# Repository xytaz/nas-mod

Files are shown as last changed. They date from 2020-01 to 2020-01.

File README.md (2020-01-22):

# NAS Mod

## Description

This project started with the objective to turn a USB RAID storage system into a NAS (Network-Attached Storage) unit. In reality, it was more of a (very much needed) exercise in embedded Linux.

The essence of the idea is to modify a [GR3680-SB3](https://www.raidsonic.de/products/external_cases/soho_raid/index_en.php?we_objectID=2984) by replacing the proprietary board with a Raspberry Pi or an ODROID-XU4. This involves:

  - Connecting the LCD, control buttons, and LED's to the new board(s) properly.
  - Interfacing Linux with this extra hardware.
  - Writing a piece of code to make use of it.

Given how surprisingly scarce, scattered, cryptic, or incomplete Linux resources on this subject can be (at least for an advanced beginner), this repo serves not only as a reference for this particular implementation but also as a tutorial for interacting with basic hardware in Linux. The emphasis is not on NAS software itself.

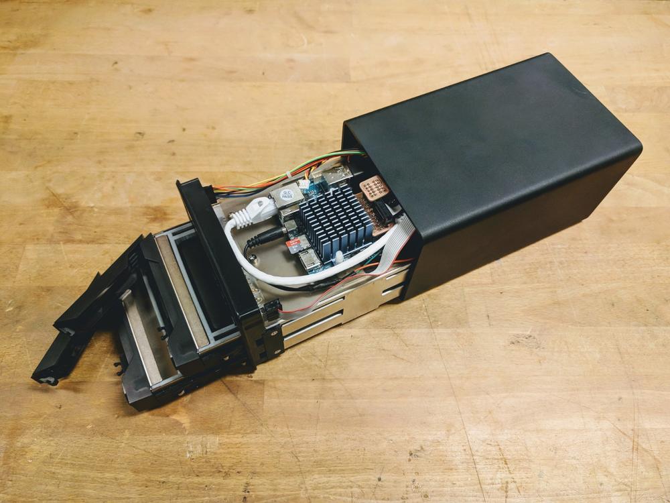
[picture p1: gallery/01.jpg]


## Quick guide

There is a number of Makefile's to automate the setup. Keep in mind that several parameters are hard-coded and things may easily break. See the detailed documentation when that happens.

Assuming you have [Linux set up](docs/02-linux-setup.md) properly, clone this repo and run `make` in each of the following directories and then reboot at the end:

- Pi
    ```
    /code/02-device-tree/pi
    /code/03-python
    /code/04-systemd-service # (manually change path in Makefile)
    ```
- XU4
    ```
    /code/01-modules
        # make NAME=charlcd
        # make NAME=charlcd
        # echo 'charlcd' | sudo tee -a /etc/modules
        # echo 'hd44780' | sudo tee -a /etc/modules
        # sudo depmod

    /code/02-device-tree/xu4
    /code/03-python
    /code/04-systemd-service # (manually change path in Makefile)
    ```

## Detailed documentation

_aka: The Missing Tutorial on How to Use Basic Hardware in Linux_

- [Hardware](docs/01-hardware.md)
- [Linux setup](docs/02-linux-setup.md)
- [How to interact with GPIO's](docs/03-gpios.md)
- [Drivers and modules](docs/04-drivers-modules.md)
- [Device tree](docs/05-device-tree.md)
- [Testing](docs/06-testing.md)
- [Python](docs/07-python.md)
- [Auto-start script](docs/08-autostart.md)

## Known issues

- Jittery backlight on startup, power off, and more.
- LCD animation better when looking at some angles (but not straight on).
- Scrolling with values that change frequently (multiple values in a line or temperature).
- Clock skipping a second occasionally.
- Last message remains after power off then on
- Not sure where these default messages come from:
    - Kernel version on startup.
    - "Power off" on shutdown.
    - "LCD driver unloaded" when `hd44780` module is removed, e.g. with `rmmod`.
    - "Reloading System ..." on reboot.

## Gallery

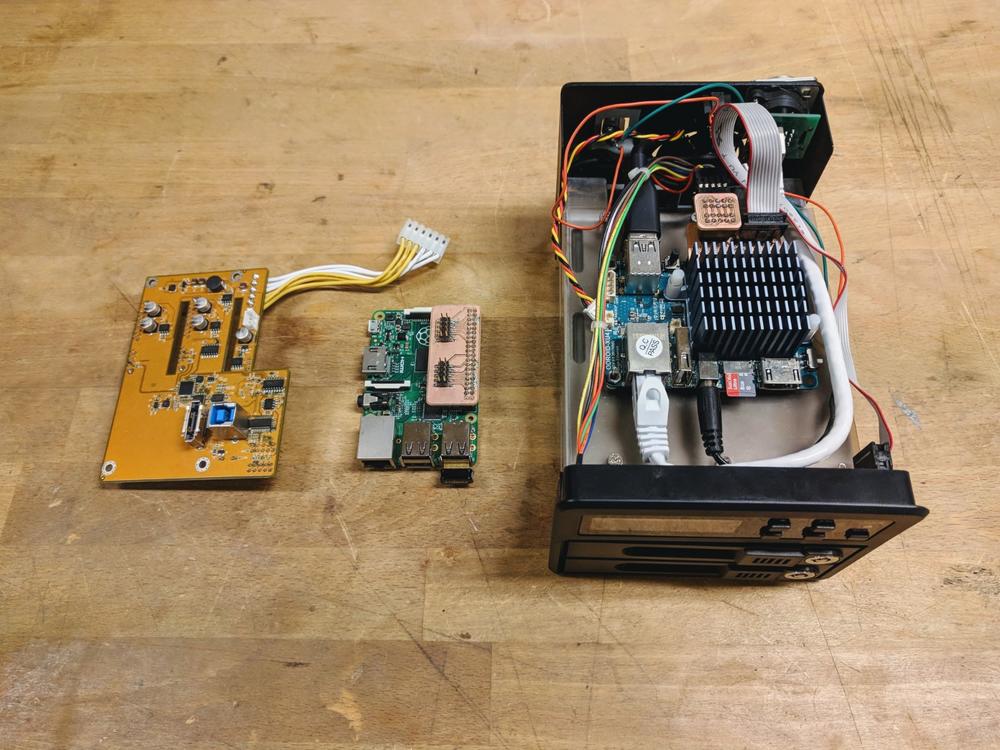
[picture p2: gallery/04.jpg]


_                   |_
--------------------|--------------------
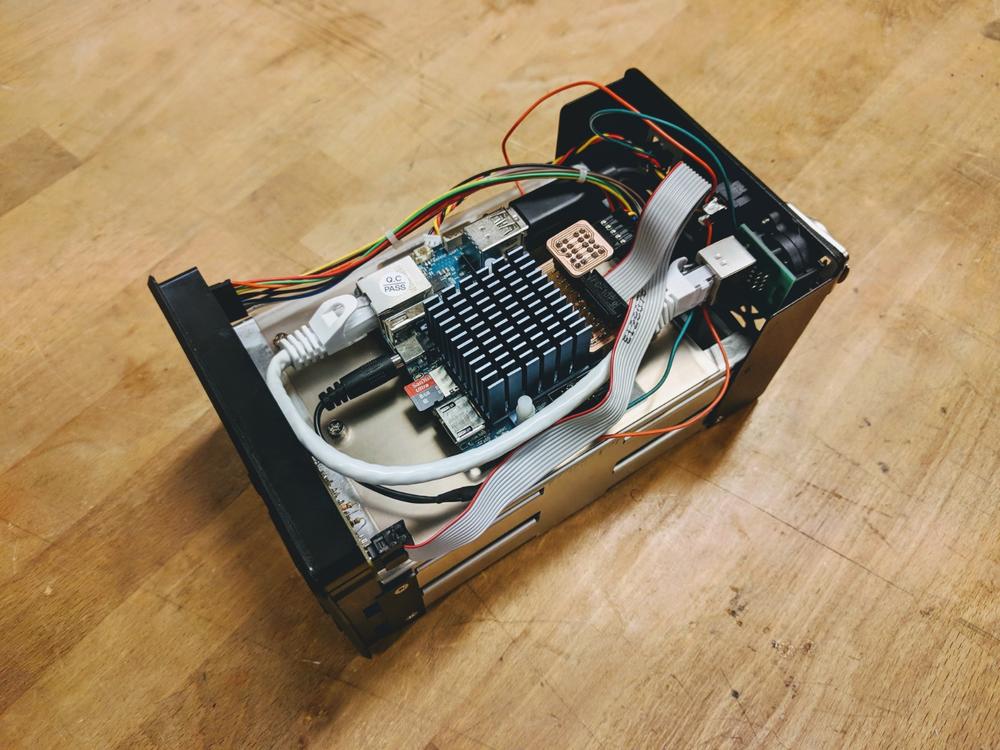
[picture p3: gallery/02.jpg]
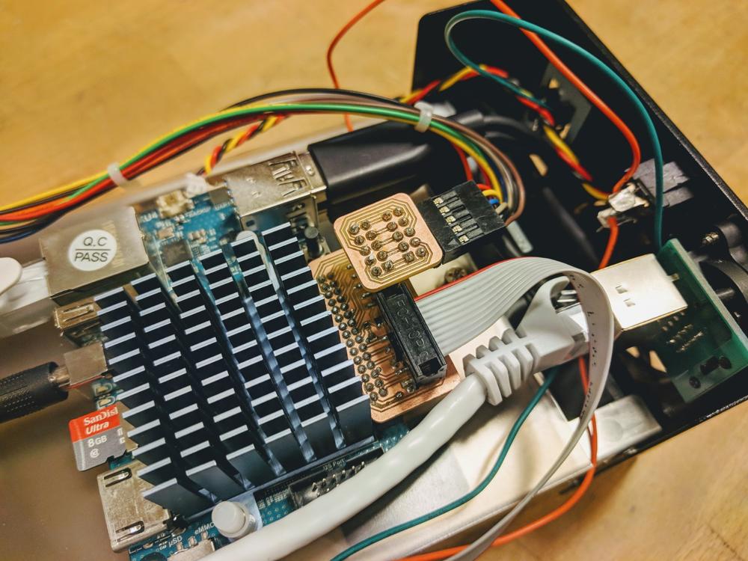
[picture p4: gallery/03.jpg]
 |  
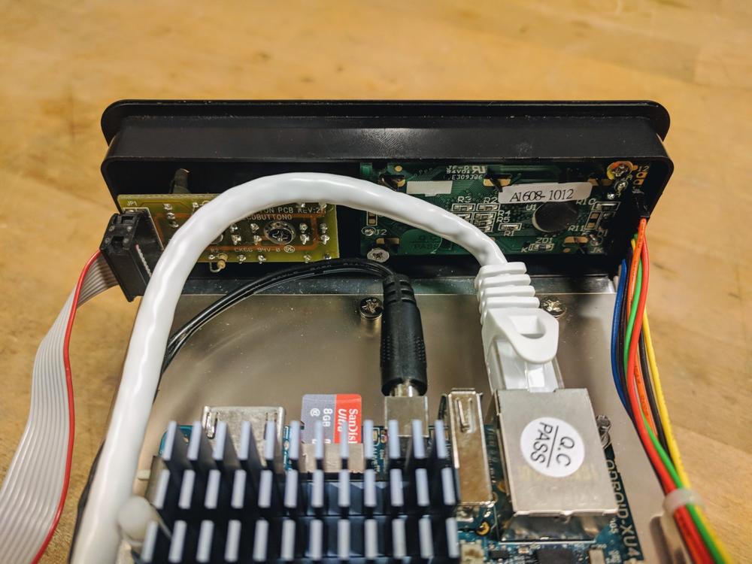
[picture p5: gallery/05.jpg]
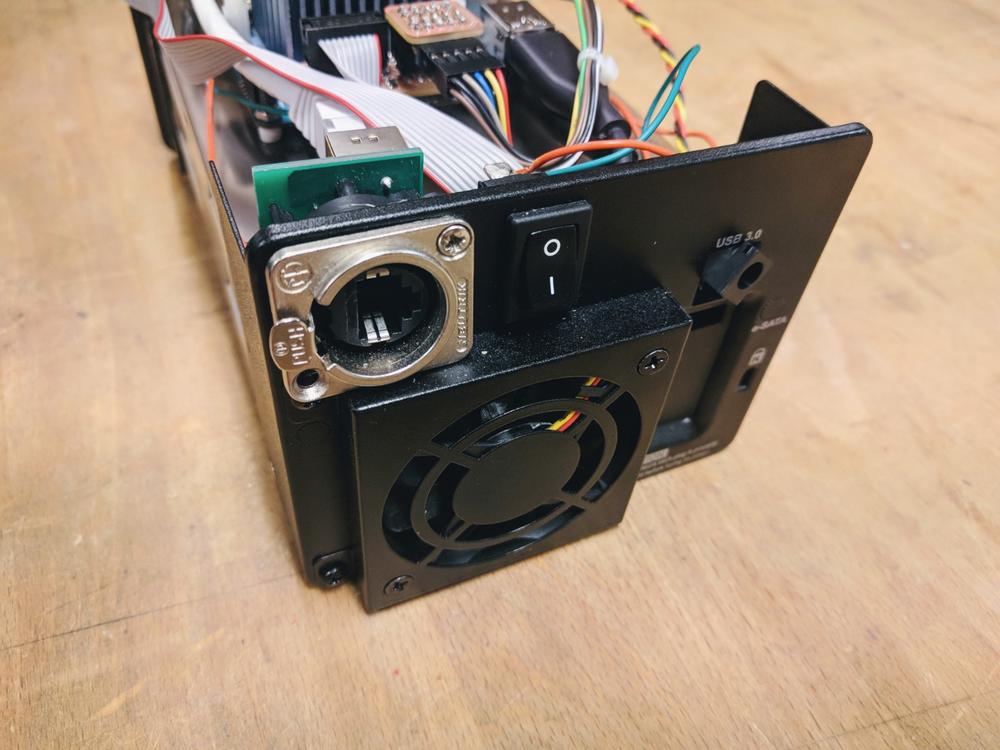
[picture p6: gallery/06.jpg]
 |  
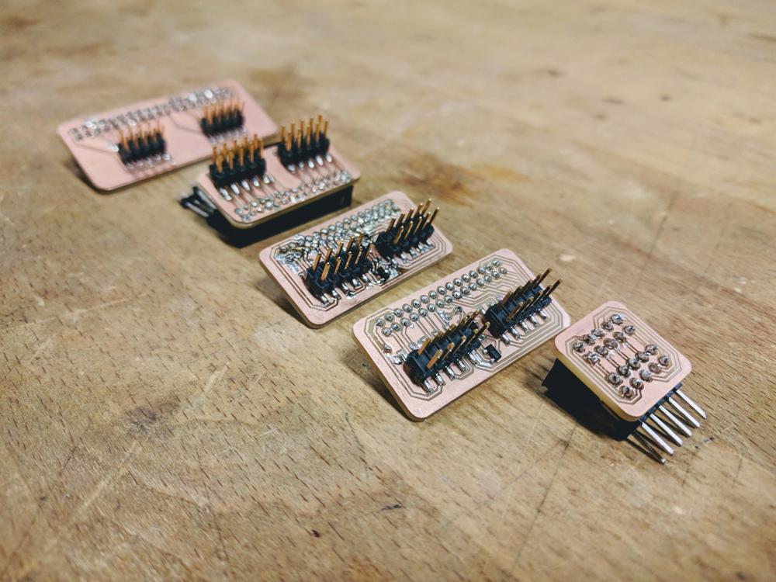
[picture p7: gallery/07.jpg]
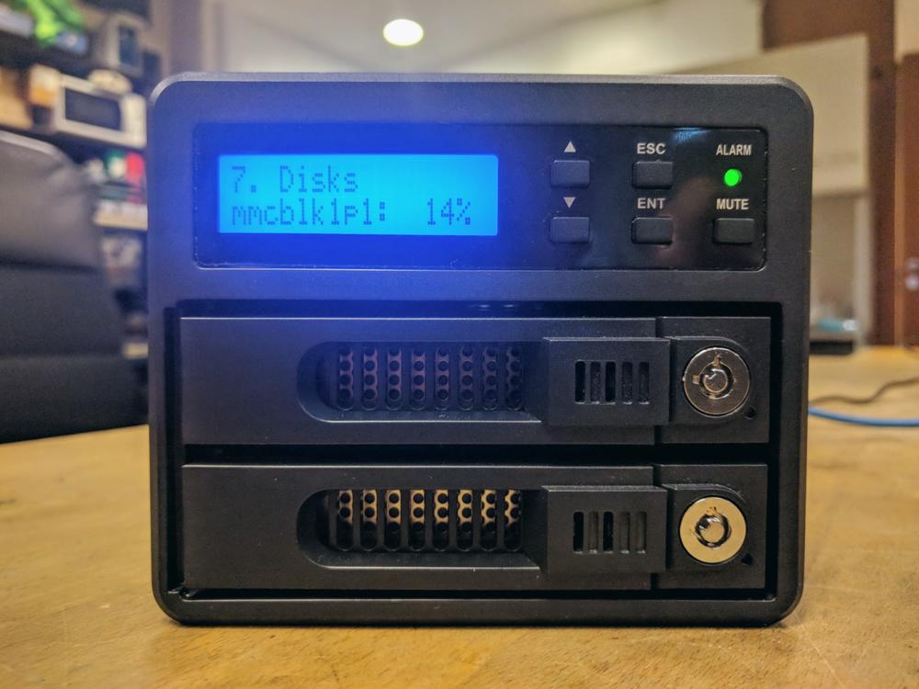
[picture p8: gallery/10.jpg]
 |

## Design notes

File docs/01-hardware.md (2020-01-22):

# NAS Mod

## Hardware

### 1. Boards

The two boards used in this project are:

- [Raspberry Pi 1 B+](https://www.adafruit.com/product/1914)
- [ODROID-XU4](https://wiki.odroid.com/odroid-xu4/odroid-xu4)

The Pi was used for prototyping even if the XU4 was meant to be the final board from the beginning. The setup on each is equivalent but not identical, as will be clear next. You obviously need only one of them.

### 2. LCD, buttons, and LED's

The GR3680-SB3 comes with:

- 16x2 LCD with the [HD44780 controller](https://en.wikipedia.org/wiki/Hitachi_HD44780_LCD_controller)
- 4 push buttons and 1 toggle button
- 2 LED's (red and green)

On the original board, the hard drives have SATA connectors and there is no way to get on a netowrk. With this mod, the actual hard drives are connected through USB. Access to the network can be done via ethernet or a [USB WiFi adapter](https://www.edimax.com/edimax/merchandise/merchandise_detail/data/edimax/global/wireless_adapters_ac1200_dual-band/ew-7822ulc/).

### 3. Connector boards

The LCD has its own connector while the buttons and LED's share one. Simple breakout boards can be milled or manufactured to connect to GPIO pins:

- [Pi pinout](https://www.raspberrypi.org/documentation/usage/gpio/)
- [XU4 pinout](https://wiki.odroid.com/odroid-xu4/hardware/expansion_connectors)

Note that:

- CON10 on the XU4 has a 2-mm pitch, which does not match the typical 2.54-mm pin spacing.
- The XU4 is a [1.8V board](https://forum.odroid.com/viewtopic.php?t=18531), which turns out to be insufficient to turn on the green LED (but surprisingly enough for the LCD data lines), hence the need for level shifting on one of the pins. There are [shields](https://www.hardkernel.com/shop/xu4-shifter-shield/) that do just that, but that is overkill for our purposes.

See the `/pcb` directory for KiCad files.

### Helpful links

- https://hackaday.com/2016/12/05/taking-it-to-another-level-making-3-3v-and-5v-logic-communicate-with-level-shifters/
- https://www.i-programmer.info/programming/hardware/9105-exploring-edison-life-at-18v.html?start=1

```
@TODO: Put somewhere

works
https://www.nexperia.com/products/bipolar-transistors/general-purpose-bipolar-transistors/transistors-single-npn/BC847C.html

weird behavior
https://cdn.sparkfun.com/datasheets/BreakoutBoards/BSS138.pdf

Also, replace symbol of transistor in schematic.
```

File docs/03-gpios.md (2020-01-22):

# NAS Mod

## How to interact with GPIO's

Two possible approaches to interact with GPIO's on a single-board computer (SBC) are:

  1. Using custom libraries designed specifically for this reason.
  2. _"The proper way",_ that is, through Linux drivers, device trees, and overlays.

The first option is generally easier but more limited. Also, more library support exists for the Raspberry Pi than any other SBC, whereas device trees are standard in every Linux kernel (with some differences).

### 1. Approach I: GPIO libraries (explored but not used)

- [gpiozero](https://gpiozero.readthedocs.io/en/stable/) is the official library for the Pi, at least it comes bundled with Raspbian Desktop. It does not support other boards.
- [WiringPi](http://wiringpi.com/) is another library designed originally for the Pi but has been [forked to support the XU4](https://wiki.odroid.com/odroid-xu4/application_note/gpio/wiringpi) in both C and Python.

Installation on the Pi is pretty straightforward. For the XU4, the following tips may save you an hour or two:
```
# Run `sudo` with all of these even if you get no complaints.
# You may get weird behavior in silence if you do not.
pip3 install --upgrade setuptools
pip3 install wheel
apt install python3-dev
pip3 install odroid-wiringpi
```

This approach was not pursued beyond installation and running a couple examples to control the LCD since it is the least simple.

Helpful links:
  
  - @REALLY_GOOD
  - [tutorials-raspberrypi.com](https://tutorials-raspberrypi.com/raspberry-pi-lcd-display-16x2-characters-display-hd44780/)
  - [glennklockwood.com](https://www.glennklockwood.com/electronics/hd44780-lcd-display.html)

  - [learn.adafruit.com](https://learn.adafruit.com/drive-a-16x2-lcd-directly-with-a-raspberry-pi?view=all)
  - [github.com](https://github.com/WiringPi/WiringPi-Python)

  - @REALLY_GOOD life savers
  - [odroid.com](https://odroid.com/dokuwiki/doku.php?id=en:16x2_lcd_io_shield)
  - [odroid.com](https://odroid.com/dokuwiki/doku.php?id=en:xu4_16x2lcd_example)

### 2. Approach II: Device trees, etc. (used)

**The short story is** that you want to be able to control hardware through the command line, typically by interacting with a _"device file"_. For this to happen (i.e. exposing that hardware to _"userspace"_), it needs to be added as a _"node"_ in the _"device tree"_. The device tree can be edited directly or, if supported, have "_device tree overlays"_ loaded on top of it on-the-fly. In either case, a device tree node needs to reference a _"driver"_ that describes how the hardware works. You could write your own drivers, but the Linux kernel comes with quite a few that may match your needs. Some of these drivers may be loaded into your particular instance of the kernel and ready to use and some not. If they are not, the corresponding _"modules"_ will need to be compiled, copied to the kernel, and enabled.

If this seems complicated, it is not, but it is the meat of this project and what took most of the time to figure out. Let us take it step by step, starting from the very end.

### Helpful links

- [All about sysfs vs. chardev](https://www.youtube.com/watch?v=lQRCDl0tFiQ)
- https://blog.adafruit.com/2018/11/26/sysfs-is-dead-long-live-libgpiod-libgpiod-for-linux-circuitpython/
- https://www.beyondlogic.org/an-introduction-to-chardev-gpio-and-libgpiod-on-the-raspberry-pi/
- https://kernel.googlesource.com/pub/scm/libs/libgpiod/libgpiod/+/v0.2.x/README.md

```
@TODO: Put somewhwere

options for interacting with gpio:
  1. [raspberry pi libraries](https://www.raspberrypi.org/documentation/usage/gpio/python/README.md)
  1. sysfs
  1. chardev, libgpiod
  1. gpio-keys
```

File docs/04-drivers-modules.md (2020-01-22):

# NAS Mod

## Drivers and modules

### 1. Check your drivers

1. First, check what drivers are ready for you to use in the kernel
```
# Find kernel version by running `uname -r`
# or more system info with `uname -a`.
> ls /lib/modules/<<KERNEL>>/kernel/drivers/
```

2. Make sure you have the following files/directories
```
# LCD
/lib/modules/<<KERNEL>>/kernel/drivers/auxdisplay/hd44780.ko
/lib/modules/<<KERNEL>>/kernel/drivers/auxdisplay/charlcd.ko
# Keys
/lib/modules/<<KERNEL>>/kernel/drivers/gpio
# LEDS
/lib/modules/<<KERNEL>>/kernel/drivers/leds
```

3. If you are using the **Pi**, go grab coffee and skip to the next section (unless any of the above is missing). If you are using the **XU4**, you get to learn more about how Linux works.

### 2. Compile your modules, enable your drivers

1. Install build tool and the correct [Linux headers](https://wiki.gentoo.org/wiki/Linux-headers)

```
> apt-get install build-essential

# Search for available header packages
> apt-cache search headers odroidxu4

# Or just go for this one
> sudo apt-get install linux-headers-current-odroidxu4
# Linux kernel headers for 5.4.7-odroidxu4 on armhf
```

2. Pull the directory `/code/modules` from this repo and navigate to it.

3. Grab modules source code

```
wget https://raw.githubusercontent.com/torvalds/linux/master/drivers/auxdisplay/charlcd.h
wget https://raw.githubusercontent.com/torvalds/linux/master/drivers/auxdisplay/charlcd.c
wget https://raw.githubusercontent.com/torvalds/linux/master/drivers/auxdisplay/hd44780.c
```

4. Compile the modules and copy the `.ko` files to the correct spot (kernel drivers directory)

```
# IMPORTANT: Run `sudo su` then run these commands.
# Does not work with regular `sudo` for some reason.
make NAME=charlcd
make NAME=hd44780
# All should be good if the last line of output does not contain the word `Error`.
```

5. (Optional) Test if the modules load properly
```
# Insert module: `insmod module.ko`
# Remove module: `rmmod module`
make test NAME=charlcd
make test NAME=hd44780
```

6. Set up modules to load on startup automatically
```
echo 'charlcd' | sudo tee -a /etc/modules
echo 'hd44780' | sudo tee -a /etc/modules
sudo depmod
```

7. Reboot
```
sudo shutdown -r now
```

8. Check if modules loaded
```
lsmod
```

9. Use `dmesg` to check any errors in the process. You may also need to debug your module at some point. Use `printk("something")` in the `.probe` function in `module.c` before compiling to `.ko` and putting it in the kernel drivers directory. Those messages will appear in `dmesg`.

### Helpful links:

- @REALLY_GOOD LKM tutorial (very good? excellent)
  - https://blog.sourcerer.io/writing-a-simple-linux-kernel-module-d9dc3762c234
  - https://stackoverflow.com/questions/4356224/how-to-load-a-custom-module-at-the-boot-time-in-ubuntu
- @REALLY_GOOD hepled a lot
  - http://swap.web.elte.hu/lcdproject/driver_en.html
  - https://www.linuxjournal.com/article/6568
  - http://linuxdocs.org/HOWTOs/Kernel-HOWTO-4.html
- headers
  - https://www.raspberrypi.org/forums/viewtopic.php?t=67347
  - https://apt.armbian.com/pool/main/l/
- https://github.com/torvalds/linux/blob/master/Documentation/devicetree/bindings/auxdisplay/hit%2Chd44780.txt

```
@TODO: Put somewhere

find / -name modprobe
/sbin/modprobe hd44780

- Config the kernel
  - Steps:
    - `cd /usr/src/linux-headers-5.4.7-odroidxu4/`
    - if you feel like it `make config` but we won't go there
    - `sudo apt install libncurses-dev`
    - `make menuconfig`
      - Device Drivers
      - Auxiliary Display Support (press Y or space without going into the item itself) ~Then go in again~ and enable HD44780?
      - 

# You may also find these files in here
# /lib/modules/<<KERNEL>>/build/drivers/

This is not sarcastic. Really.
  - `If you don't understand what all this is about, say N.`

recompile kernel?
  - /proc/config.gz
  - look up "gen2"

  for future:
  - compile kernel
    http://www.ibiblio.org/elemental/howto/kernel-rebuild.html
```

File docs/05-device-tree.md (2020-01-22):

# NAS Mod

## Device trees and overlays

### 1. The basics

Each system loads up a base device tree file in the format `.dtb` (device tree binary blob) which contains all the hardware nodes defined.

- First, you can see the effects of the device tree loaded.
```
ls /proc/device-tree/
```

- There does not seem to be a one-step way to track down the actual `.dtb` file, but it is not that difficult. A big hint is the model name.
```
cat /proc/device-tree/model
```

- `.dtb` files are typically somewhere under the `/boot` directory. You should be able to identify the correct `.dtb` file based on the model name you have.
```
# Pi
/boot/bcm2708-rpi-b-plus.dtb
# XU4
/boot/dtb/exynos5422-odroidxu4.dtb
```

- You can convert a `.dtb` file into `.dts`, a human-readable device tree source file.
```
# From blob to source
dtc -O dts -o output.dts input.dtb # or .dtbo
```

- Ideally, you would not want to touch the base `.dts`. This is where overlays come into the picture. These are files with only additional nodes that should be added to the base device tree on-the-fly. An overlay file starts as a `.dts` and should be compiled to a `.dtbo` file.
```
# From source to blob
dtc -O dtb -o output.dtbo input.dts # or .dtb
```

- Overlays are not supported on all systems. You can till by the existence of a `/boot/overlays` directory. The good news is you get to see how both ways work since the Pi has it and the XU4 does not.

Before you continue, it is worth getting familiar with device tree structure and conventions. Keep the following links handy as you go through the upcoming steps:

  - https://elinux.org/Device_Tree_Reference
  - https://elinux.org/Device_Tree_Usage
  - https://www.raspberrypi.org/documentation/configuration/device-tree.md

### 2. Make changes

- With overlays (Pi)

  1. Create `dts` file(s)
  2. Compile to `dtbo`
  3. Copy to `/boot/overlays`
  4. Enable overlays in `/boot/config.txt`
  5. Disable conflicting nodes (I2C)
  6. Reboot

- Without overlays (XU4)

  1. Decompile base device tree `.dtb`
  2. Add nodes to `.dts`
  3. Compile back to `.dtb`
  4. Disable conflicting nodes (SPI)
  5. Copy to original spot (`boot/dtb`)
  6. Reboot

Navigate to `/code/device-tree` and check out the files there or simply run `make` in the corresponding directory for these steps to execute.

If you decide to take a look at the files mentioned, here is a quick summary of the main differences between the Pi and XU4:

| | Pi | XU4 |
| --- | --- | --- |
| Overlays | Supported | Not supported |
| DT location | `/boot/` and `/boot/overlays` | `/boot/dtb`|
| Use of `&gpio` | Enabled | Have to use `phandle` of `gpx1`, etc. | 
| Numbers | Decimal | Hex |

#### 2.1 Pin numbering

If you take a look at the [pinout of, say, the XU4](https://wiki.odroid.com/odroid-xu4/hardware/expansion_connectors), you will see quite a few ways to refer to a pin:
  1. Pin number
  2. GPIO number
  3. WiringPi Number
  4. xN.M format (or whatever it is actually called)

The second and the fourth are the ones used here, summarized (nicely!) in the table below:

```
| ------- | ----- | ---------- | ---- | -------------------------- |
|         | label |  key code  |  pi  |  xu4       (PCP* PN**)     |
| ------- | ----- | ---------- | ---- | -------------------------- |
| sw2     |  dwn  |     108    |  19  |  24  x2.0  (0x48 0x00)     |
| sw3     |  up   |     103    |   6  |  25  x2.1  (0x48 0x01)  +  |
| sw5     |  ent  |      28    |   0  |  31  x2.7  (0x48 0x07)     |
| sw1a    |  mute |      58    |  11  | 174  a0.3  (0xb0 0x03)     |
| sw4     |  esc  |       1    |   9  |  28  x2.4  (0x48 0x04)     |
| ------- | ----- | ---------- | ---- | -------------------------- |
| led2    |  red  |            |  13  |  23  x1.7  (0x4a 0x07)     |
| led1    |  grn  |            |   5  |  19  x1.3  (0x4a 0x03)     |
| ------- | ----- | ---------- | ---- | -------------------------- |
| rst     |       |            |  22  | 210  b3.3  (0xcf 0x03)     |
| en      |       |            |  27  | 209  b3.2  (0xcf 0x02)     |
| d4      |       |            |  17  | 189  a2.4  (0x47 0x04)     |
| d5      |       |            |   4  | 172  a0.1  (0xb0 0x01)     |
| d6      |       |            |   3  | 171  a0.0  (0xb0 0x00)     |
| d7      |       |            |   2  | 173  a0.2  (0xb0 0x02)  +  |
| ------- | ----- | ---------- | ---- | -------------------------- |
 * Pin controller phandle (in hex). Values may change from system to system.
   Check `/code/device-tree/xu4/nas-nodes.txt` to see how these values are found.
** Pin number (in hex), e.g. the "1" in "x3.1".
```

#### 2.2 What is _"Disable conflicting nodes"_ all about?

**Symptoms**

  - (Pi) Gibberish output on the LCD.
  - (XU4) Failure to load the LCD module. Running `dmesg` results in:
  ```
  hd44780: probe of auxdisplay failed with error -16
  ```

**Debugging**

Error 16 indicates that two processes are trying to access the same resource at the same time.

Placing `printk` messages and checking `dmesg`, as described in the section discussing drivers and modules, points to the point of failure, i.e. one of the pins failing to register properly.

Running `gpioinfo` (`apt-get install gpiod`) will show which pins are busy and by what.

Note: Debugging on the XU4 was more systematic. It was more based on hunch with the Pi, since the symptoms and results of the previous debugging steps differ significantly.

**Diagnosis**

Some pins double as regular GPIO's as well as special-purpose pins. It happens that a few of the pins are also for I2C (Pi) and SPI (XU4). This depends entirely on which pins you decide(d) to use.

**Solution**

You could choose to use only pure GPIO pins, but that is not necessary in this case.

- With overlays (Pi)
  - Disable the offending node in `/boot/config.txt`
  ```
  # Change from ...
  dtparam=i2c_arm=on
  # ... to
  dtparam=i2c_arm=off
  ```

- Without overlays (XU4)
  - Option I: _Manually_ disable the offending node in the base device tree
  ```
  # Change from ...
  spidev@0 {
        status = "okay";
  # ... to
  spidev@0 {
        status = "disabled";
  ```

  - Option 2: Disable it slightly [more elegantly](https://developer.ridgerun.com/wiki/index.php/Edit_device_tree_at_run_time) (on the `.dtb` not `.dts`)
  ```
  fdtput exynos5422-odroidxu4.dtb spi1/spidev@0 status disabled
  # Also check out `fdtget` to read values.
  ```

### Helpful links

- https://yeah.nah.nz/embedded/linux-chardev-lcd/
- http://blog.gegg.us/2017/01/setting-up-a-gpio-button-keyboard-on-a-raspberry-pi/
- https://reitmaier.xyz/blog/matrix_keyboard/
- http://blog.gegg.us/2017/08/a-matrix-keypad-on-a-raspberry-pi-done-right/
- https://www.acmesystems.it/CM3-HOME_rgbled
- http://xillybus.com/tutorials/device-tree-zynq-1
- https://elinux.org/images/e/e5/Dt_debugging_part_3.pdf
- https://www.milesburton.com/USD_LCD_Display_(HD44780)_Running_on_Linux_via_Arduino
- https://www.rototron.info/lcdproc-tutorial-for-raspberry-pi/
- https://stackoverflow.com/questions/21670967/how-to-compile-dts-linux-device-tree-source-files-to-dtb
- When you decide to give up and RTFM
  - https://elinux.org/Device_Tree_Reference
  - https://elinux.org/Device_Tree_Usage
  - https://elinux.org/Device_Tree_Source_Undocumented
  - https://www.raspberrypi.org/documentation/configuration/device-tree.md
  - https://www.kernel.org/doc/Documentation/devicetree/bindings/input/gpio-keys.txt
  - https://github.com/torvalds/linux/blob/master/Documentation/devicetree/bindings/auxdisplay/hit%2Chd44780.txt
  - https://www.kernel.org/doc/Documentation/devicetree/bindings/pinctrl/pinctrl-bindings.txt
  - https://www.kernel.org/doc/Documentation/devicetree/bindings/pinctrl/brcm,bcm2835-gpio.txt
  
```
@TODO: Put somewhere
user space vs. kernel space (device tree is kernel space)

sudo find /sys/ -name *pin*
ls /sys/kernel/debug/pinctrl
find /sys/ -name *pinmux*
sudo cat /sys/kernel/debug/pinctrl/

http://wiringpi.com/the-gpio-utility/
gpio readall -a
```

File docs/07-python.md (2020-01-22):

# NAS Mod

## Python

### TITLE?

To set up the environment, navigate to `/code/python` and run with `sudo`:

```
apt-get update
apt-get -y install python3-pip
pip3 install -r requirements.txt
python3 nas.py
```

To make changes to the code, your entry point is `/code/python/nas.py`. The files should be straightforward to navigate.

To make it easy to grasp what is going on:

- The LCD has a list of screens and an index to track which screen is currently active.
- Each screen has a list of lines.
- Each line has a list of values and an index to track which value is currently active.
- The value of a line can be static (string or list of strings) or dynamic (function).
- There is a set of threads to listen to presses of specific keys.
- There is a refresh thread that constantly checks if the values of dynamic lines have changed.
- There is a scrolling thread, which can be disabled, to horizontally scroll content that is longer than the screen can display.

### Helpful links
- [LCD Arduino video tutorial](https://www.youtube.com/watch?v=Q58mQFwWv7c)
- [LCD Pi video tutorial](https://www.youtube.com/watch?v=cVdSc8VYVBM)

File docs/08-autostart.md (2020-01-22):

# NAS Mod

## Auto-start script

### `systemd` service

Lastly, one of the ways to run a script on startup is by creating a `systemd` service.

See `/code/service/nas.service` for an example to use with the following steps.

1. Create a `<NAME>.service` file.
2. Copy to correct directory
```
sudo cp <NAME>.service /lib/systemd/system/
```
3. Change permissions
```
sudo chmod 644 /lib/systemd/system/<NAME>.service
```
4. Reload to register service
```
sudo systemctl daemon-reload
```
5. Enable service
```
sudo systemctl enable <NAME>.service
```
6. Reboot
```
sudo shutdown -r now
```

The service should be running. You can check by running `systemctl`.

In case something goes wrong, you can read the logs to debug. Python errors will show up here in the case the script fails at some point.
```
journalctl -u <NAME>.service
# You can also manage the service at any point
# sudo systemctl stop/start/restart <NAME>.service
```

If you decide to disable a service:
```
sudo systemctl disable <NAME>.service
```
Remember to remove service files in `/lib/systemd/system/` if you aim for complete deletion.

@CONFIRM Restart the service whenever you update the code (obviously), and also reload it (not so obvious).

### Helpful links:

- https://www.dexterindustries.com/howto/run-a-program-on-your-raspberry-pi-at-startup/
- https://scruss.com/blog/2017/10/22/creating-a-systemd-user-service-on-your-raspberry-pi/
- https://unix.stackexchange.com/questions/225401/how-to-see-full-log-from-systemctl-status-service
- https://superuser.com/questions/513159/how-to-remove-systemd-services
- https://www.freedesktop.org/software/systemd/man/systemd.unit.html

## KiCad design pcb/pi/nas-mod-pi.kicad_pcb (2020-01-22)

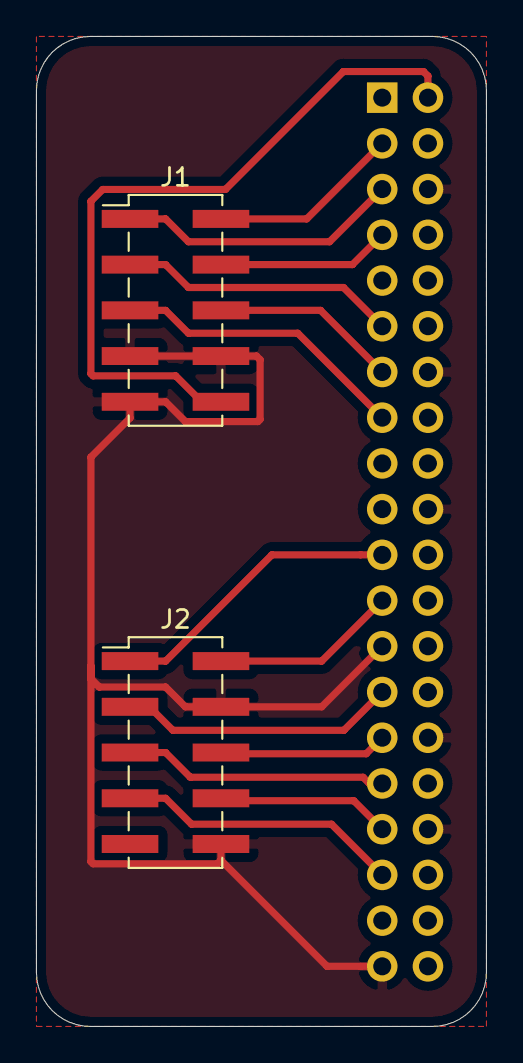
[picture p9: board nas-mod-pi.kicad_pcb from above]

Board: 2 copper layers, 25.0 x 55.0 mm, 3 parts (1 on the bottom side), 16 nets.

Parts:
J1, J2: Conn_02x05_Odd_Even; PinHeader_2x05_P2.54mm_Vertical_SMD
J3: Conn_02x20_Odd_Even; PinSocket_2x20_P2.54mm_Vertical

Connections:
/3V3: J3.1, J3.17
/5V: J1.10, J3.2, J3.4
/D0: J1.3, J3.11
/D1: J1.4, J3.7
/D2: J1.1, J3.5
/D3: J1.2, J3.3
/EN: J1.6, J3.13
/GND: J1.7, J1.8, J1.9, J2.4, J2.10, J3.6, J3.9, J3.14, J3.20, J3.25, J3.30, J3.34, J3.39
/LED1: J2.6, J3.29
/LED2: J2.8, J3.33
/RST: J1.5, J3.15
/SW1a: J2.2, J3.23
/SW2: J2.7, J3.35
/SW3: J2.5, J3.31
/SW4: J2.1, J3.21
/SW5: J2.3, J3.27

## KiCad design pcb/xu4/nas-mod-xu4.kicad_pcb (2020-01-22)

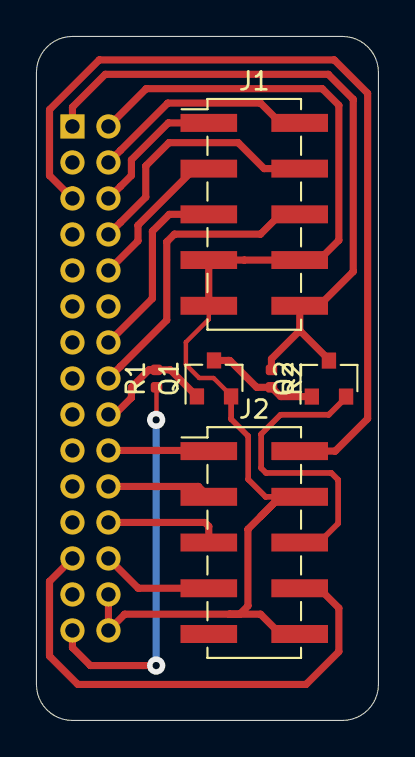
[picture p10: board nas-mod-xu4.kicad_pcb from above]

Board: 2 copper layers, 19.0 x 38.0 mm, 7 parts (1 on the bottom side), 18 nets.

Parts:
J1, J2: Conn_02x05_Odd_Even; PinHeader_2x05_P2.54mm_Vertical_SMD
J3: Conn_02x15_Odd_Even; PinSocket_2x15_P2.00mm_Vertical
Q1, Q2: BSS138; SOT-23
R1, R2: 10K; R_0402_1005Metric

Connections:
/1V8: J3.29, R1.1
/5V: J1.10, J3.1, Q2.3, R2.1
/D4: J1.3, J3.10
/D5: J1.4, J3.8
/D6: J1.1, J3.6
/D7: J1.2, J3.4
/EN: J1.6, J3.16
/GND: J1.7, J1.8, J1.9, J2.4, J2.10, J3.2, J3.28, J3.30, Q1.2
/LED1: J2.6, Q2.2
/LED1-SGNL: J3.18, Q1.1, R1.2
/LED2: J2.8, J3.25
/RST: J1.5, J3.14
/SW1a: J2.2, J3.5
/SW2: J2.7, J3.26
/SW3: J2.5, J3.24
/SW4: J2.1, J3.20
/SW5: J2.3, J3.22
unnamed: Q1.3, Q2.1, R2.2

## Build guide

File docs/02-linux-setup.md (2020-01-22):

# NAS Mod

## Linux setup

### 1. Pi

**On your machine**

1. Download image: [Raspbian Buster Lite, September 2019](https://www.raspberrypi.org/downloads/raspbian/)
2. Uncompress
  ```
  # Check correct file path
  > unzip 2019-09-26-raspbian-buster-lite.zip
  ```
3. Write to SD card
```
# Check correct file path
# Check correct device path `dev/sdX` by running `lsblk -p`
> dd bs=4M if=2019-09-26-raspbian-buster-lite.img of=/dev/sdX conv=fsync status=progress
```

**On the Pi**

4. Insert SD card and connect board to a computer display and a keyboard
```
# Default Raspberry credentials: pi/raspberry
```
5. Get ip address (assuming ethernet connection)
```
> ip a
```
6. Enable `avahi`
``` 
> sudo apt-get install avahi-daemon avahi-discover avahi-utils libnss-mdns mdns-scan
# The board should now be accessible at: ssh pi@raspberry.local
``` 
7. [Check configuration](https://www.raspberrypi.org/documentation/configuration/raspi-config.md)
```
> sudo raspi-config
# Required changes: enable ssh (Interfacing Options > SSH)
# Recommended changes: password, hostname, expand filesystem, timezone
```
8. Confirm distro (not really needed)
```
> lsb_release -a
Description:  Raspbian GNU/Linux 10 (buster)
```
9. Confirm kernel
```
> uname -r
4.19.75+
```

Helpful links:
  - [raspberrypi.org](https://www.raspberrypi.org/documentation/installation/installing-images/linux.md)

### 2. XU4

**On your machine**

1. Download image: [Armbian Buster minimal 5.4](https://www.armbian.com/odroid-xu4/#kernels-archive-all)
2. Uncompress
  ```
  # Check correct file path
  > 7za e Armbian_19.11.7_Odroidxu4_buster_current_5.4.3_minimal.7z
  ```
3. Write to SD card
```
# Check correct file path
# Check correct device path `dev/sdX` by running `lsblk -p`
> dd bs=4M if=Armbian_19.11.7_Odroidxu4_buster_current_5.4.3_minimal.img of=/dev/sdX conv=fsync status=progress
```

**On the XU4**

4. Insert SD and connect board to a computer display and a keyboard
```
# Default Armbian credentials: root/1234
# Create another user if prompted to
```
5. Get ip address (assuming ethernet connection)
```
> ip a
```
6. Enable `avahi`
``` 
> sudo armbian-config
# Then go to: System > Avahi
# The board should now be accessible at: ssh USERNAME@odroidxu4.local
``` 
7. Update kernel
```
> sudo armbian-config
# Then go to: System > Other (Switch to other kernel)
```
8. Confirm distro (not really needed)
```
> lsb_release -a
Description:  Debian GNU/Linux 10 (buster)
```
9. Confirm kernel
```
> uname -r
5.4.7-odroidxu4
```

### 3. Extra notes

  - `avahi` may take a minute or two to kick in after it is first enabled/installed. Also, the machine you are accessing from should have `avahi-resolve` installed on it:
  ```
  > sudo apt-get install avahi-daemon avahi-discover avahi-utils libnss-mdns mdns-scan
  ```

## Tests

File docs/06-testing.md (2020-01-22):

# NAS Mod

## Testing

### TITLE?

Hoping that you did not get any errors following the steps so far, what is left to do is test and see if what you have set up actually works.

- **General** Newly created device tree nodes should show up as their own directories and files.
```
ls /proc/device-tree/
```
LED's may be under the `leds` directory in there.

- **LCD** The LCD should be available as a [device file `/dev/lcd`](https://sites.google.com/site/mincepi/pi2hd44780) which you can write to.
```
echo -e -n "\e[2JHello,\nWorld!" > /dev/lcd
```

- **Buttons** The buttons where defined to simulate keyboard keys instead of having to manage GPIO's manually. Input devices typically have their own event which can be monitored.
```
# For live monitoring of events.
# Make sure you install it first `apt-get install evtest`
evtest

# OR browse input device files
ls /dev/input
cat /dev/input/eventX
```

- **LED's** LED's can be managed by reading and writing through `sysfs`. You [may need to do `sudo su`](https://raspberrypi.stackexchange.com/questions/22213/why-does-sudo-not-work-in-this-case).
```
echo 1 > /sys/class/leds/nas-led1/brightness
echo heartbeat > /sys/class/leds/nas-led2/trigger
```

- **Debugging** Many things could go wrong. The first place to check for error messages is `dmesg`. On the Pi, There is a handy `sudo vcdbg log msg` that shows the steps of loading a device tree and the overlays and the status of each.

### Helpful Links

- https://www.kernel.org/doc/Documentation/devicetree/bindings/leds/common.txt
- https://raspberrypi.stackexchange.com/questions/697/how-do-i-control-the-system-leds-using-my-software

```
@TODO: Put somewhere

echo 29 > /sys/class/gpio/export
echo out > /sys/class/gpio/gpio29/direction
echo 1 > /sys/class/gpio/gpio29/value
```

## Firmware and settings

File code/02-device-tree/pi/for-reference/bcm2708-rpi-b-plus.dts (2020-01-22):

/dts-v1/;

/memreserve/	0x0000000000000000 0x0000000000001000;
/ {
	compatible = "raspberrypi,model-b-plus\0brcm,bcm2835";
	model = "Raspberry Pi Model B+";
	interrupt-parent = < 0x01 >;
	#address-cells = < 0x01 >;
	#size-cells = < 0x01 >;

	aliases {
		serial0 = "/soc/serial@7e201000";
		serial1 = "/soc/serial@7e215040";
		audio = "/soc/audio";
		aux = "/soc/aux@7e215000";
		sound = "/soc/sound";
		soc = "/soc";
		dma = "/soc/dma@7e007000";
		intc = "/soc/interrupt-controller@7e00b200";
		watchdog = "/soc/watchdog@7e100000";
		random = "/soc/rng@7e104000";
		mailbox = "/soc/mailbox@7e00b880";
		gpio = "/soc/gpio@7e200000";
		uart0 = "/soc/serial@7e201000";
		sdhost = "/soc/mmc@7e202000";
		mmc0 = "/soc/mmc@7e202000";
		i2s = "/soc/i2s@7e203000";
		spi0 = "/soc/spi@7e204000";
		i2c0 = "/soc/i2c@7e205000";
		uart1 = "/soc/serial@7e215040";
		spi1 = "/soc/spi@7e215080";
		spi2 = "/soc/spi@7e2150c0";
		mmc = "/soc/mmc@7e300000";
		mmc1 = "/soc/mmc@7e300000";
		i2c1 = "/soc/i2c@7e804000";
		i2c2 = "/soc/i2c@7e805000";
		usb = "/soc/usb@7e980000";
		leds = "/leds";
		fb = "/soc/fb";
		thermal = "/soc/thermal@7e212000";
		axiperf = "/soc/axiperf";
		ethernet0 = "/soc/usb@7e980000/usb1@1/usbether@1";
	};

	chosen {
		bootargs = "coherent_pool=1M";
	};

	thermal-zones {

		cpu-thermal {
			polling-delay-passive = < 0x00 >;
			polling-delay = < 0x3e8 >;
			thermal-sensors = < 0x02 >;
			coefficients = < 0xfffffde6 0x635d8 >;
			phandle = < 0x27 >;

			cooling-maps {
			};
		};
	};

	soc {
		compatible = "simple-bus";
		#address-cells = < 0x01 >;
		#size-cells = < 0x01 >;
		ranges = < 0x7e000000 0x20000000 0x2000000 >;
		dma-ranges = < 0x40000000 0x00 0x20000000 >;
		phandle = < 0x28 >;

		txp@7e004000 {
			compatible = "brcm,bcm2835-txp";
			reg = < 0x7e004000 0x20 >;
			interrupts = < 0x01 0x0b >;
			status = "disabled";
			phandle = < 0x29 >;
		};

		dma@7e007000 {
			compatible = "brcm,bcm2835-dma";
			reg = < 0x7e007000 0xf00 >;
			interrupts = < 0x01 0x10 0x01 0x11 0x01 0x12 0x01 0x13 0x01 0x14 0x01 0x15 0x01 0x16 0x01 0x17 0x01 0x18 0x01 0x19 0x01 0x1a 0x01 0x1b 0x01 0x1b 0x01 0x1b 0x01 0x1b 0x01 0x1c >;
			interrupt-names = "dma0\0dma1\0dma2\0dma3\0dma4\0dma5\0dma6\0dma7\0dma8\0dma9\0dma10\0dma11\0dma12\0dma13\0dma14\0dma-shared-all";
			#dma-cells = < 0x01 >;
			brcm,dma-channel-mask = < 0x7f35 >;
			phandle = < 0x08 >;
		};

		watchdog@7e100000 {
			compatible = "brcm,bcm2835-pm\0brcm,bcm2835-pm-wdt";
			#power-domain-cells = < 0x01 >;
			#reset-cells = < 0x01 >;
			reg = < 0x7e100000 0x114 0x7e00a000 0x24 >;
			clocks = < 0x03 0x15 0x03 0x1d 0x03 0x17 0x03 0x16 >;
			clock-names = "v3d\0peri_image\0h264\0isp";
			system-power-controller;
			phandle = < 0x1f >;
		};

		cprman@7e101000 {
			compatible = "brcm,bcm2835-cprman";
			#clock-cells = < 0x01 >;
			reg = < 0x7e101000 0x2000 >;
			clocks = < 0x04 0x05 0x00 0x05 0x01 0x05 0x02 0x06 0x00 0x06 0x01 0x06 0x02 >;
			firmware = < 0x07 >;
			phandle = < 0x03 >;
		};

		rng@7e104000 {
			compatible = "brcm,bcm2835-rng";
			reg = < 0x7e104000 0x10 >;
			interrupts = < 0x02 0x1d >;
			phandle = < 0x20 >;
		};

		mailbox@7e00b880 {
			compatible = "brcm,bcm2835-mbox";
			reg = < 0x7e00b880 0x40 >;
			interrupts = < 0x00 0x01 >;
			#mbox-cells = < 0x00 >;
			phandle = < 0x16 >;
		};

		gpio@7e200000 {
			compatible = "brcm,bcm2835-gpio";
			reg = < 0x7e200000 0xb4 >;
			interrupts = < 0x02 0x11 0x02 0x12 >;
			gpio-controller;
			#gpio-cells = < 0x02 >;
			interrupt-controller;
			#interrupt-cells = < 0x02 >;
			pinctrl-names = "default";
			phandle = < 0x0d >;

			dpi_gpio0 {
				brcm,pins = < 0x00 0x01 0x02 0x03 0x04 0x05 0x06 0x07 0x08 0x09 0x0a 0x0b 0x0c 0x0d 0x0e 0x0f 0x10 0x11 0x12 0x13 0x14 0x15 0x16 0x17 0x18 0x19 0x1a 0x1b >;
				brcm,function = < 0x06 >;
				phandle = < 0x2a >;
			};

			emmc_gpio22 {
				brcm,pins = < 0x16 0x17 0x18 0x19 0x1a 0x1b >;
				brcm,function = < 0x07 >;
				phandle = < 0x2b >;
			};

			emmc_gpio34 {
				brcm,pins = < 0x22 0x23 0x24 0x25 0x26 0x27 >;
				brcm,function = < 0x07 >;
				brcm,pull = < 0x00 0x02 0x02 0x02 0x02 0x02 >;
				phandle = < 0x2c >;
			};

			emmc_gpio48 {
				brcm,pins = < 0x30 0x31 0x32 0x33 0x34 0x35 >;
				brcm,function = < 0x07 >;
				phandle = < 0x15 >;
			};

			gpclk0_gpio4 {
				brcm,pins = < 0x04 >;
				brcm,function = < 0x04 >;
				phandle = < 0x2d >;
			};

			gpclk1_gpio5 {
				brcm,pins = < 0x05 >;
				brcm,function = < 0x04 >;
				phandle = < 0x2e >;
			};

			gpclk1_gpio42 {
				brcm,pins = < 0x2a >;
				brcm,function = < 0x04 >;
				phandle = < 0x2f >;
			};

			gpclk1_gpio44 {
				brcm,pins = < 0x2c >;
				brcm,function = < 0x04 >;
				phandle = < 0x30 >;
			};

			gpclk2_gpio6 {
				brcm,pins = < 0x06 >;
				brcm,function = < 0x04 >;
				phandle = < 0x31 >;
			};

			gpclk2_gpio43 {
				brcm,pins = < 0x2b >;
				brcm,function = < 0x04 >;
				brcm,pull = < 0x00 >;
				phandle = < 0x32 >;
			};
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
